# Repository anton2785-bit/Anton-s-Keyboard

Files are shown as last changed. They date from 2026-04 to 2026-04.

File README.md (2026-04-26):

# Anton-s-Keyboard
---

## What is this project

* This project is just a keyboard using 2 PCB layers. It has hotswapable switches and LEDs bellow every cap. The little oled screen will be used for brightens and lighting for the led. The rotary encoder will be volume controll. 
---
## Why i made this project
* My keyboard is starting to have some switches a little more squishi or lose compared to others. Also some of the keycaps are worn down.
* In conclusion I want to change my old keyboard with this one. 
---
# Schematic

* The shematic could be a little bit of a mess, but i had made it a month prior to this moment.
  Schematic

---
# PCB

* The PCB was redone 1 time, so that it was better with the lenght of traces and minimising the resistance.

Top layer PCB
Back layer PCB

---
# 3D case

* The case isnt perfect, but for now it will work. When i get all of the parts for the keyboard and then I will have the ability to measuer all of the things I need to make the case more percise. 
Keyboard case


* Note: The case will be 3d printed by my friend and cost free. But I will maka corections on the case once i gen the whole thing and i have the propper dimensions for the holes and the usb cable going towards the Microcontroller. 

--- 
# Firmware
* The firmware will be changed once I get access to the microcontroller.
* The code now is generated by gemini. 
* 

--- 
# Assembly steps
* First the smaller parts must be souldered first because it will be harder to soulder the smaller components once the larger ones are placed / souldered.
* Secondly the larger components are souldered.
* Thirdly the foam is placed in the bottom case.
* After that all of the other parts are placed on the foam and closed off with the top plate.
* Finaly the cable can be connected to the PC and keyboard.

---
# BOM

| Component | Purpose | Qty | Cost (USD) | Distributor |
|---|---|-----|---|---|
| Gateron Stabilizers | Prevents larger keys from wobbling | 1 lot | $9.45 | Gateron |
| Capacitors 100nF | Noise decoupling for LEDs | 2 lots | $1.61 | AliExpress |
| 5V Level Shifter (74AHCT125) | Data line shifter for LEDs | 1 | $2.95 | AliExpress |
| LEDs (SK6812 Mini-E) | Per-key underglow LEDs | 2 lots | $3.56 | AliExpress |
| Keycaps | Keycaps | 1 set | $15.78 | AliExpress |
| Rotary Encoder (EC11E) | Volume/scroll knob | 1 | $2.78 | AliExpress |
| Diodes (1N4148W) | Prevent signal backflow in matrix | 2 lots | $1.84 | AliExpress |
| OLED Screen (0.91" 128x32) | Info display | 1 | $2.35 | AliExpress |
| Tantalum Capacitor (470µF 6.3V) | Bulk power decoupling for LEDs | 1 | $3.94 | AliExpress |
| Resistors (4.7kΩ and 350Ω) | Pull-up and current limiting | 1 pack | $4.10 | AliExpress |
| Foam | Sound dampening under PCB | 1 | $7.77 | AliExpress |
| Coiled Cable | Keyboard cable | 1 | $10.77 | AliExpress |
| PCB | Board fabrication | 1 | $51.00 | JLCPCB |
| Microcontroller (YD-RP2040) | Main controller | 1 | $2.94 | AliExpress |
| Gateron Switches | Mechanical switches | 1 set | $29.00 | Gateron |
| Hotswap Sockets | Easy switch swapping | 1 lot | $6.68 | Gateron |
| **Total** | | | **$156.52** | |

---
# Aditional notes on the design choices
* The bulk capacitors and the voltage regulator if for the data line going to the LEDs on the PCB.
* The case as mentioned above " will be 3d printed by my friend and cost free. But I will maka corections on the case once i gen the whole thing and i have the propper dimensions for the holes and the usb cable going towards the Microcontroller. "
--- 
# Credits

* Designed and built by (Anton/ Anton-2785-bit)
* Inspired by open‑source mechanical keyboard and hackpad communities (https://stasis.hackclub.com/dashboard).

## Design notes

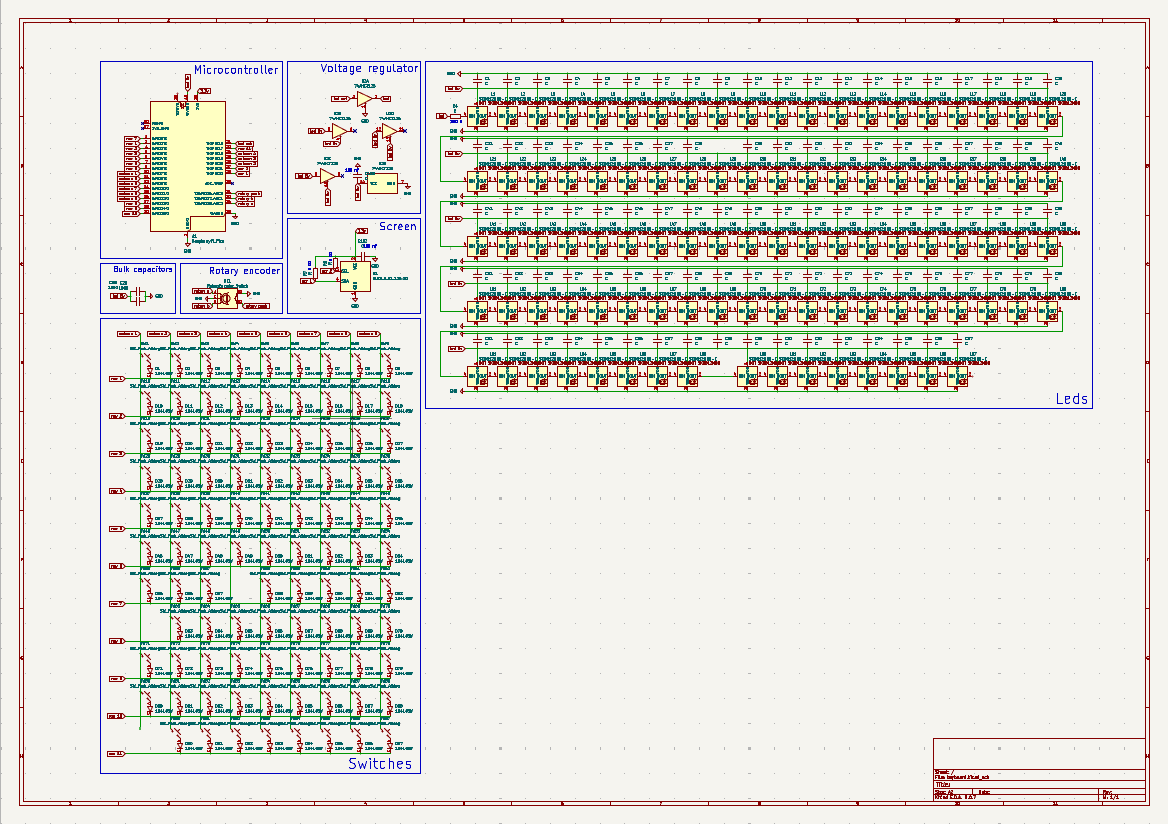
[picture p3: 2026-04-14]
Images/Schematic.png

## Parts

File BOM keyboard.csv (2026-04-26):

Product name | Product description | Product link | Product price | Product amount | Product total
Microcontroller (YD-RP 2040) | The microcontroller for the keyboard | Aliexpress | ? 2.94 | 1 | ? 2.94
Gateroon switches | These are the switches that you type on | Gateron | ? 29.00 | 1 | ? 31.94
Hotswap module | These modules allow for the easy change of the switches | Gateron | ? 6.68 | 1 | ? 38.62
Gateroon stabilizer | makes the bigger switches not wable | gateron | ? 9.45 | 1 | ? 48.07
decoupling capacitors ( 100nF ) | The capacitors are for lowering the electrical noise before the LEDs | Aliexpress | ? 1.61 | 2 | ? 51.29
5V level shifter (74AHCT125) | A 5V level shifter for the data line on the LEDs | Aliexpress | ? 2.95 | 1 | ? 54.24
LEDs (SK 6812 mini E) | The LEDs bellow the switches | Aliexpress | ? 3.56 | 2 | ? 61.36
keycaps | Keycaps | Aliexpress | ? 15.78 | 1 | ? 77.14
Rotary encoder ( EC11E ) | A knob for twisting | Aliexpress | ? 2.78 | 1 | ? 79.92
Diodes ( 1N4148W ) | Diodes, that stop form signal going back | Aliexpress | ? 1.84 | 2 | ? 83.60
Oled screen ( 0.91 inch screen 128x32) | A mini screen for displaying information | Aliexpress | ? 2.35 | 1 | ? 85.95
Tantalum capacitor ( 470uF 6.3V D ) | A bulk capacitor | Aliexpress | ? 3.94 | 1 | ? 89.89
Resistors ( Pack of many ) | Resistors ( 4.7 k? and 350?) | Aliexpress | ? 4.10 | 1 | ? 93.99
PCB | PCB | JLCPCB | ? 45.00 | 1 | ? 138.99
Foam | Used for making the keyboard sound betetr, its placed bellow the PCB | Aliexpress | ? 7.77 | 1 | ? 146.76

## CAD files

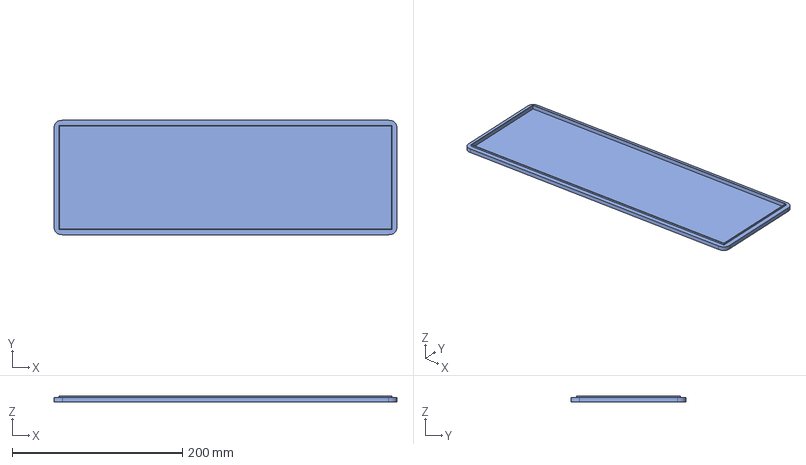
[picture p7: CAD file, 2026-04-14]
CAD/Keyboard case both parts v1/Part Studio 1 - Part 2.step
403.4 x 134.7 x 7.00 mm

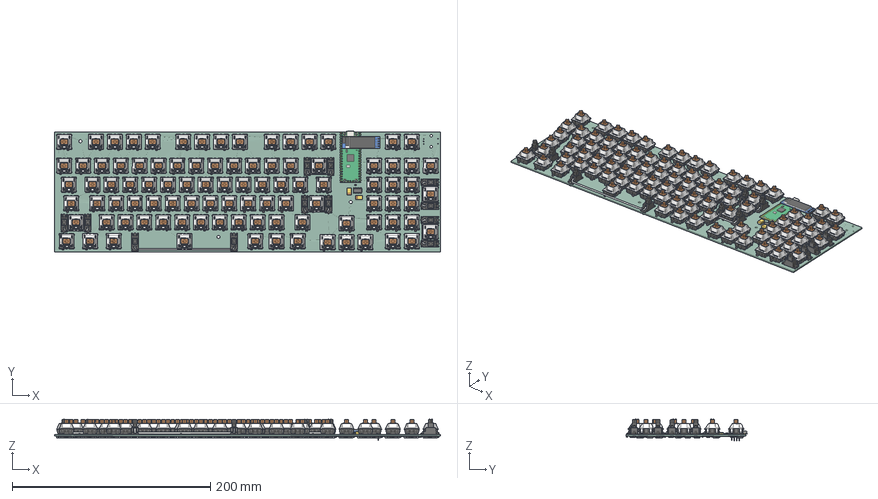
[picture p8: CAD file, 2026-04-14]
CAD/keyboard.step
389.6 x 122.3 x 21.7 mm
Pins x 96
CP_EIA-7343-31_Kemet-D x 2
C_0805_2012Metric x 98
Hotswap_MX x 96
MX_Plate x 96
Stabilizer_MX_2.00u x 5
Stabilizer_MX_6.25u
SOIC-14_3.9x8.7mm_P1.27mm
RaspberryPi_Pico_Module_KiCad
OLED_0.91_128x32
Pin Header 4 x 1 TH 2.54mm Pitch
RESC-0603 x 13
2SD0601A
Diode_SOD-123 x 96
R_0805_2012Metric x 3
keyboard_PCB

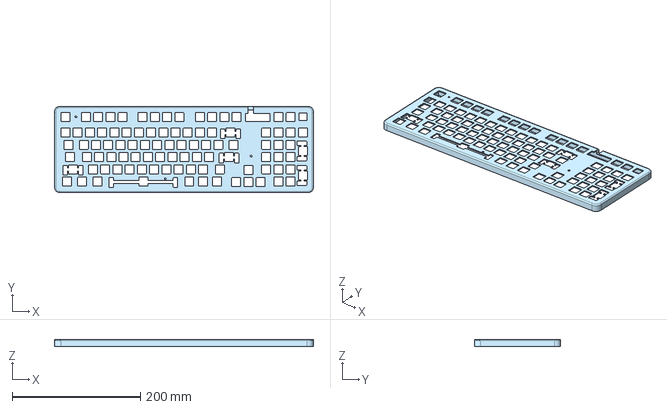
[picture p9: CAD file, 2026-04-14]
CAD/Keyboard case both parts v1/Part Studio 1 - Part 1.step
403.4 x 134.7 x 11.5 mm

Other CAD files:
Production/Bottom case.stl
Production/Top plate.stl

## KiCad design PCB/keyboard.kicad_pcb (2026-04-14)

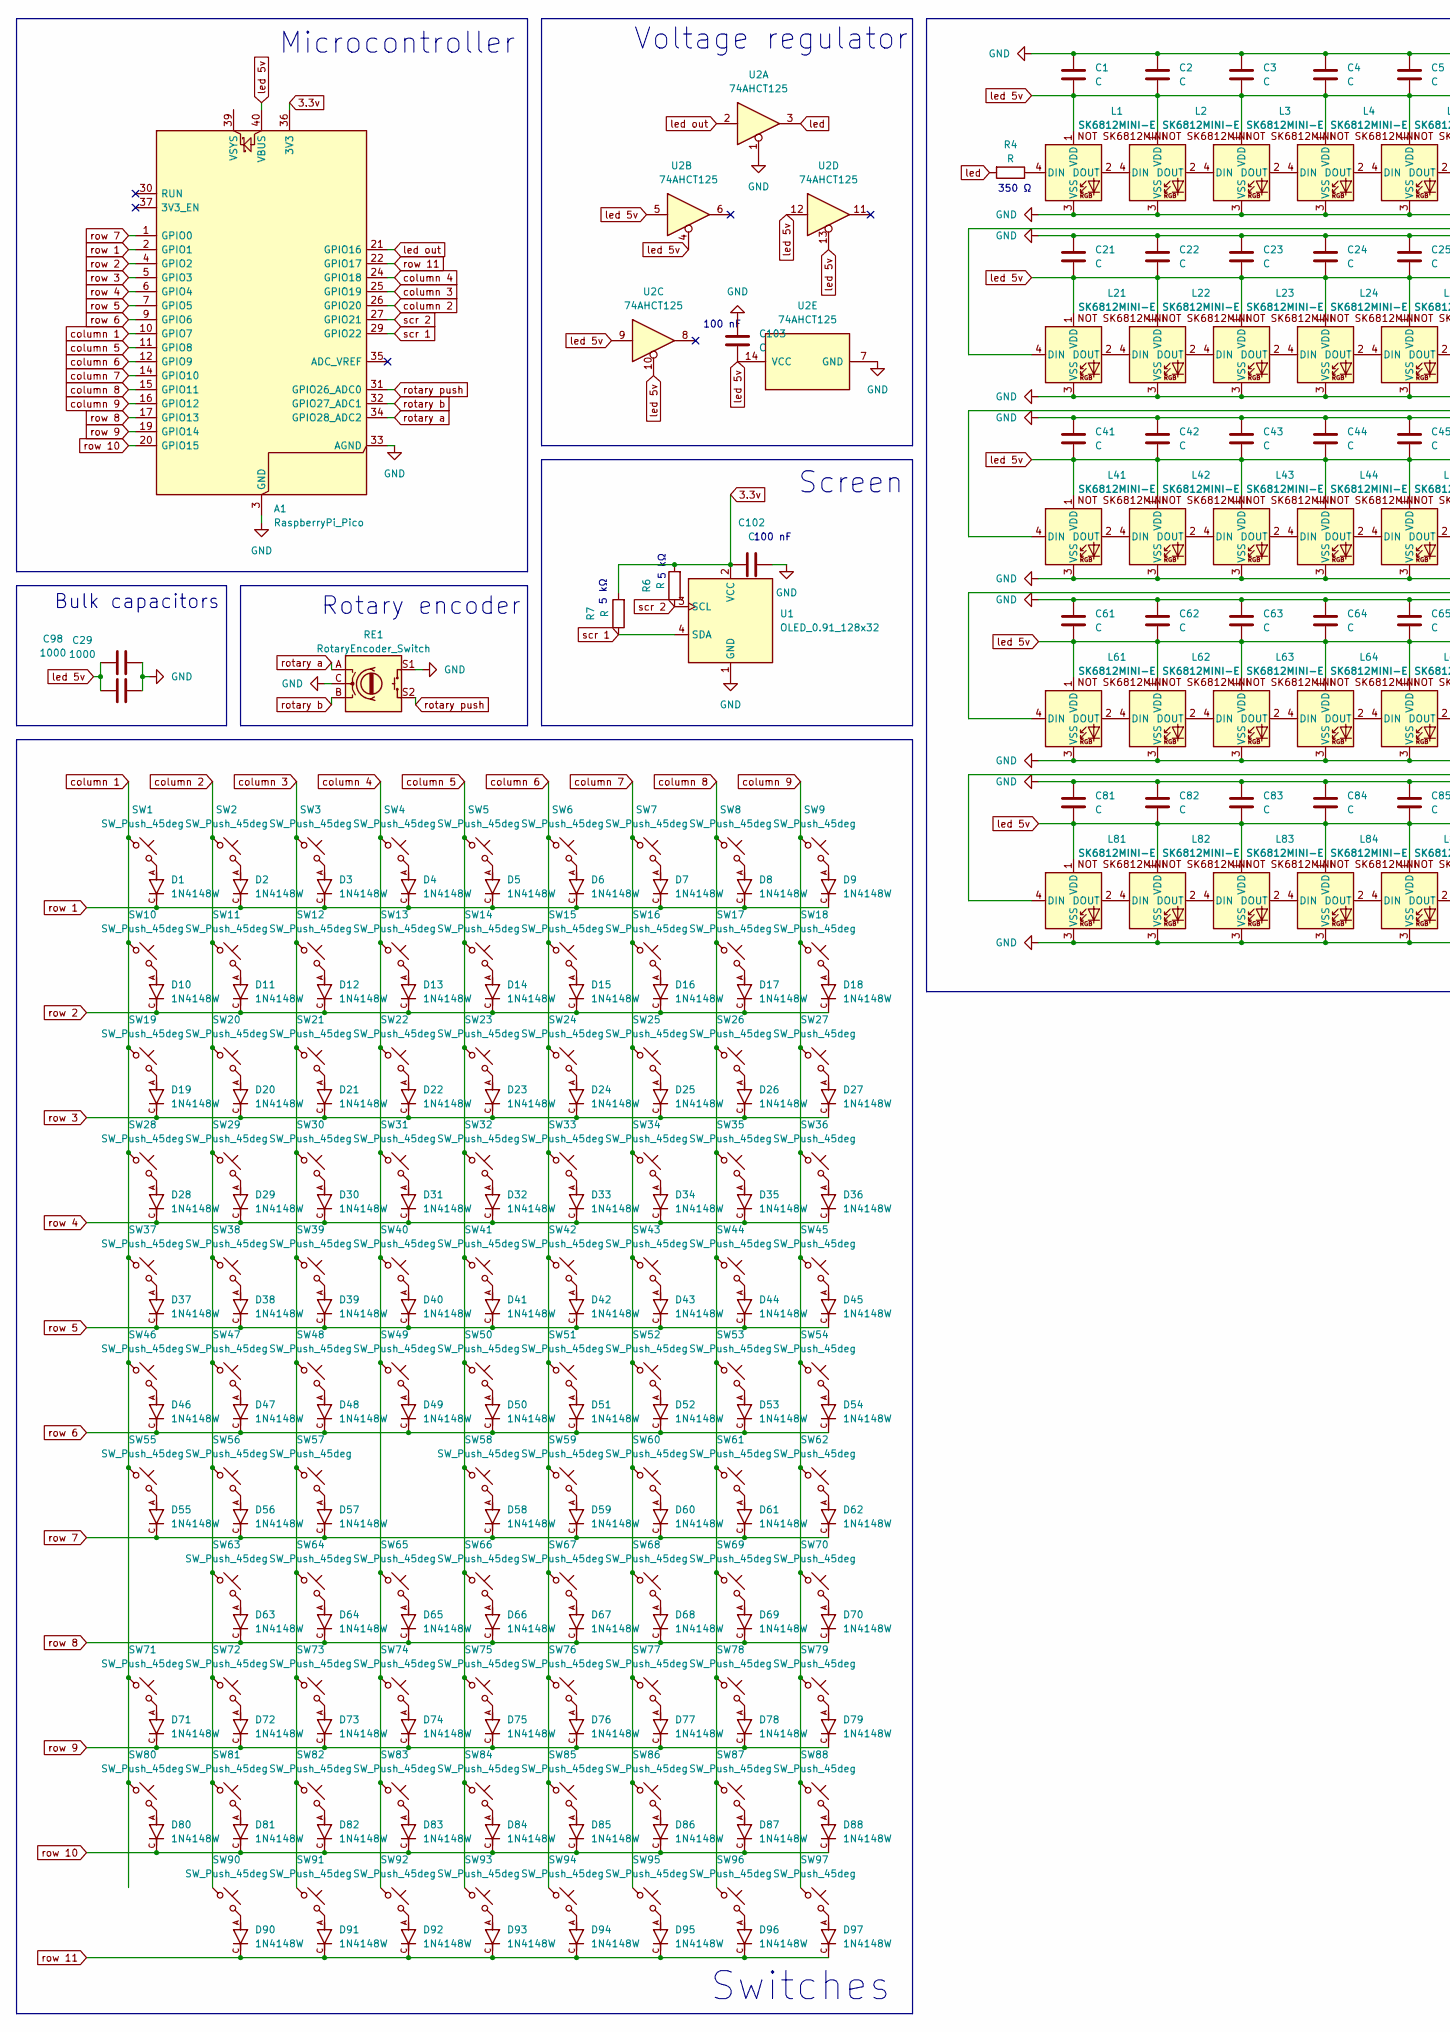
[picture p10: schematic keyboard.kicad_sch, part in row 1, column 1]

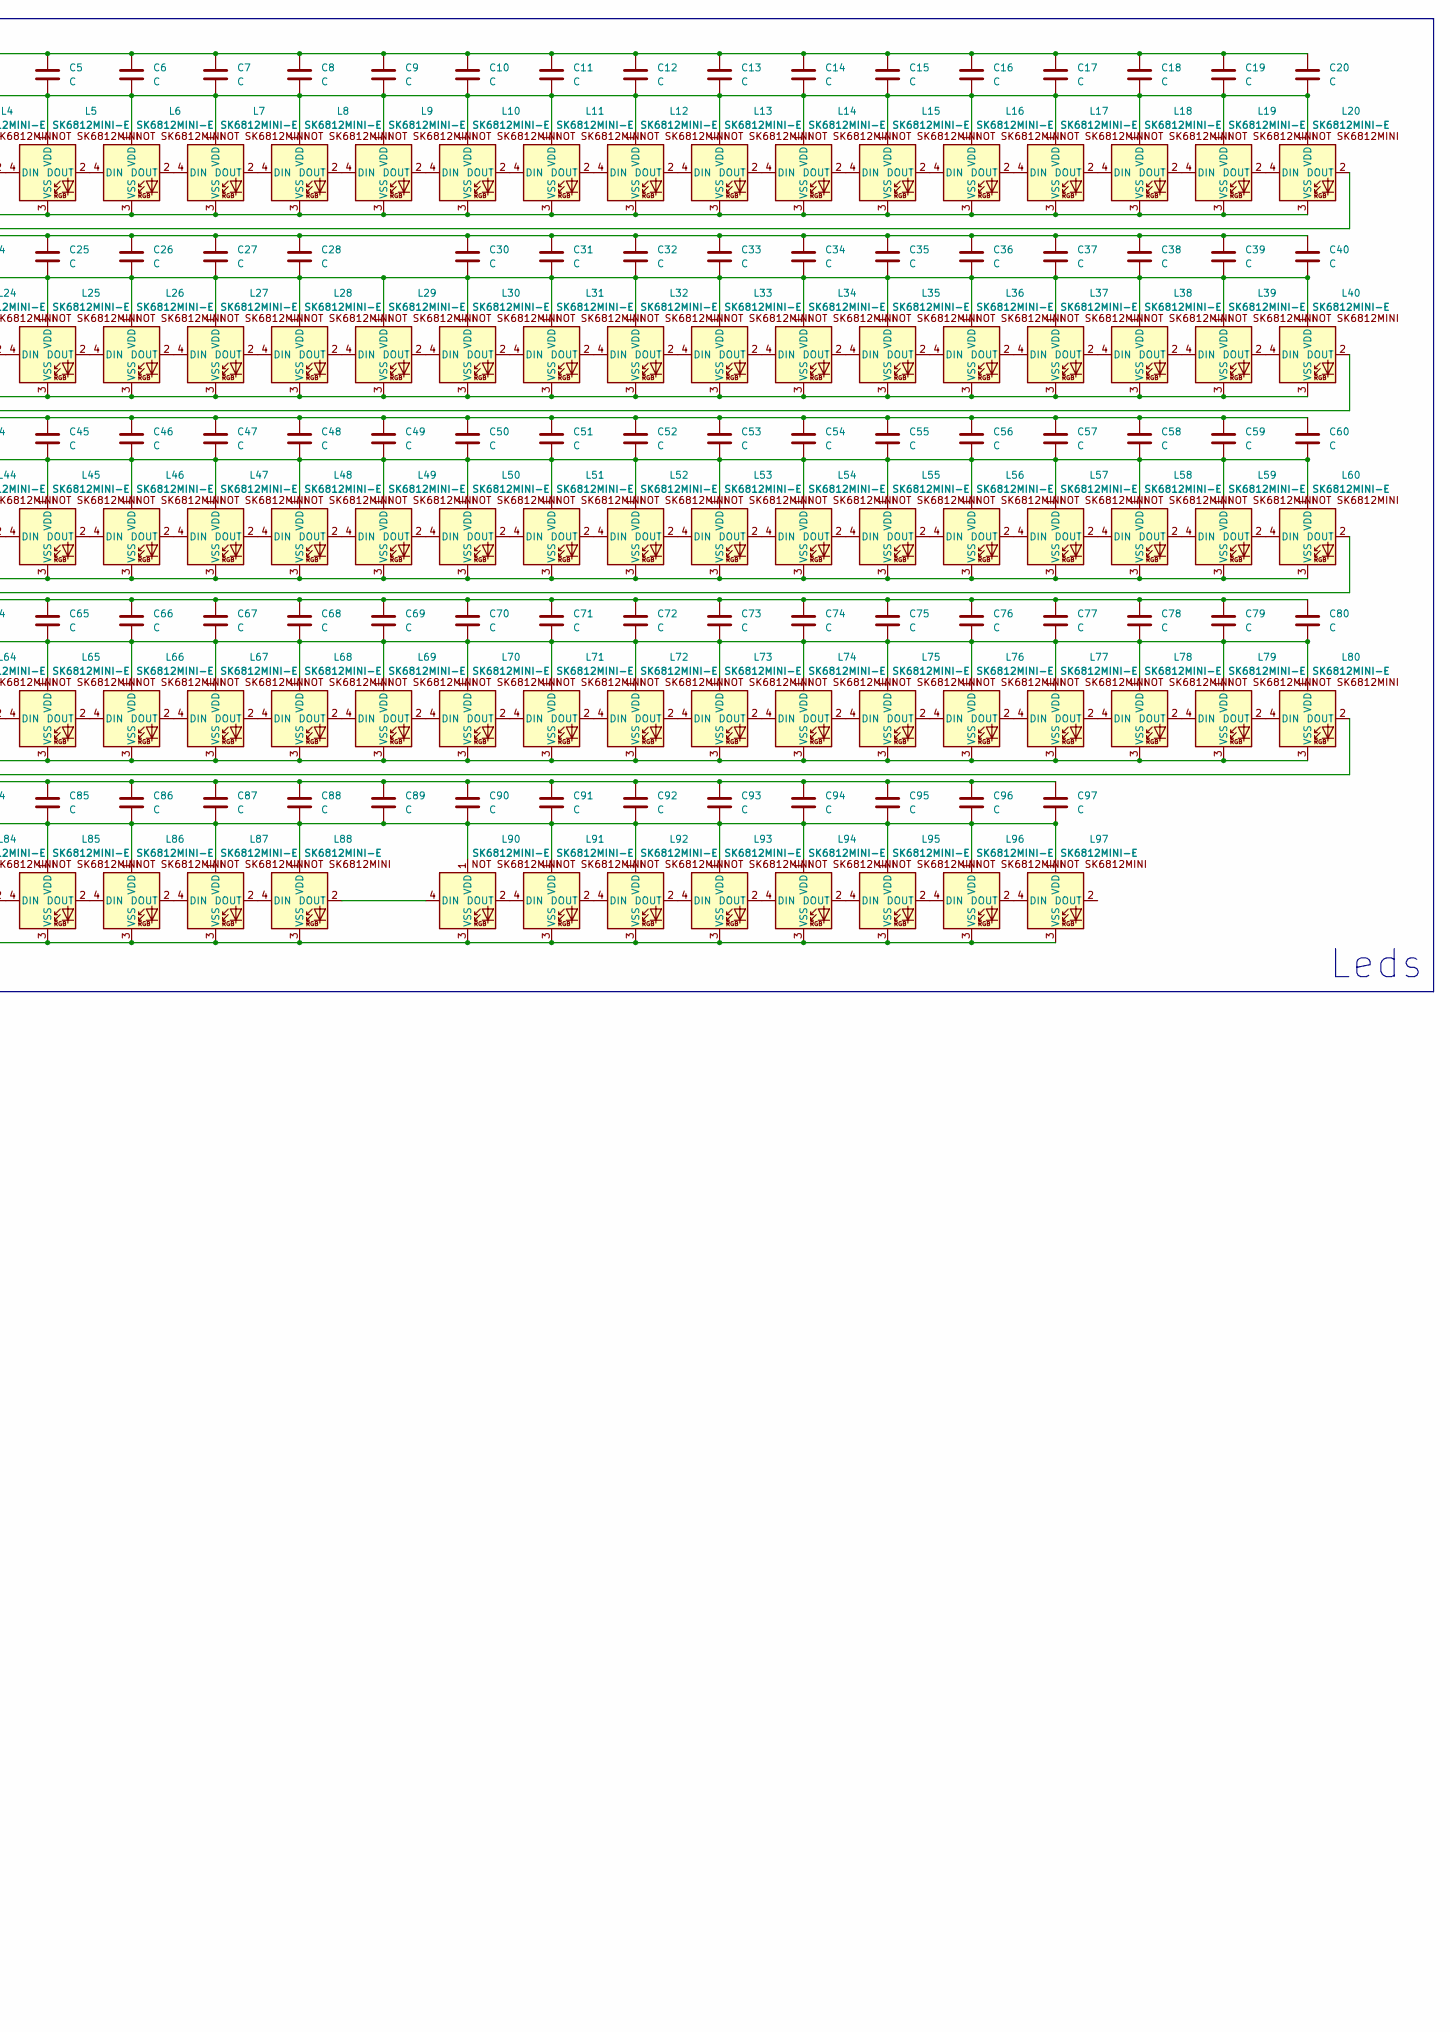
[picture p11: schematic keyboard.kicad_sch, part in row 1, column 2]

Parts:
A1: RaspberryPi_Pico; RaspberryPi_Pico_SMD_HandSolder
C1, C2, C3, C4, C5, C6, C7, C8, C9, C10, C11, C12, C13, C14, C15, C16, C17, C18, C19, C20, C21, C22, C23, C24, C25, C26, C27, C28, C30, C31, C32, C33, C34, C35, C36, C37, C38, C39, C40, C41, C42, C43, C44, C45, C46, C47, C48, C49, C50, C51, C52, C53, C54, C55, C56, C57, C58, C59, C60, C61, C62, C63, C64, C65, C66, C67, C68, C69, C70, C71, C72, C73, C74, C75, C76, C77, C78, C79, C80, C81, C82, C83, C84, C85, C86, C87, C88, C89, C90, C91, C92, C93, C94, C95, C96, C97, C102, C103: C; C_0805_2012Metric_Pad1.18x1.45mm_HandSolder
C29, C98: 1000; CP_EIA-7343-31_Kemet-D_HandSolder
D1, D2, D3, D4, D5, D6, D7, D8, D9, D10, D11, D12, D13, D14, D15, D16, D17, D18, D19, D20, D21, D22, D23, D24, D25, D26, D27, D28, D29, D30, D31, D32, D33, D34, D35, D36, D37, D38, D39, D40, D41, D42, D43, D44, D45, D46, D47, D48, D49, D50, D51, D52, D53, D54, D55, D56, D57, D58, D59, D60, D61, D62, D63, D64, D65, D66, D67, D68, D69, D70, D71, D72, D73, D74, D75, D76, D77, D78, D79, D80, D81, D82, D83, D84, D85, D86, D87, D88, D90, D91, D92, D93, D94, D95, D96, D97: 1N4148W; SODFL3816X120N; PARTREV 2021-07-12
L1, L2, L3, L4, L5, L6, L7, L8, L9, L10, L11, L12, L13, L28, L29, L30, L31, L32, L33, L34, L35, L36, L37, L38, L39, L40, L41, L55, L56, L57, L58, L59, L60, L61, L62, L63, L64, L65, L66, L67, L68, L69, L70, L74, L75, L76, L80, L81: SK6812MINI-E; MX_sk6812_mini_e_v1
L14, L15, L16, L17, L18, L19, L20, L21, L22, L23, L24, L25, L26, L27, L42, L43, L44, L45, L46, L47, L48, L49, L50, L51, L52, L53, L54, L71, L72, L73, L77, L78, L79, L82, L83, L84, L85, L86, L87, L88, L90, L91, L92, L93, L94, L95, L96, L97: SK6812MINI-E; MX_sk6812_mini_e_v1_rotated
R4, R6, R7: R; R_0805_2012Metric_Pad1.20x1.40mm_HandSolder
RE1: RotaryEncoder_Switch; RotaryEncoder_Alps_EC11E-Switch_Vertical_H20mm_CircularMoun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
SW1, SW2, SW3, SW4, SW5, SW6, SW7, SW8, SW9, SW10, SW11, SW12, SW13, SW14, SW15, SW16, SW17, SW18, SW20, SW21, SW22, SW23, SW24, SW25, SW26, SW27, SW29, SW30, SW31, SW32, SW33, SW34, SW35, SW36, SW38, SW39, SW40, SW41, SW42, SW43, SW44, SW45, SW53, SW54, SW55, SW56, SW57, SW58, SW59, SW60, SW61, SW62, SW63, SW64, SW65, SW67, SW68, SW69, SW70, SW72, SW73, SW74, SW76, SW77, SW78, SW79, SW80, SW81, SW82, SW83, SW86, SW87, SW88, SW90, SW91, SW93, SW94, SW95, SW96, SW97: SW_Push_45deg; Hotswap_MX_1.00u
SW19, SW75: SW_Push_45deg; Hotswap_MX_1.50u
SW28, SW84: SW_Push_45deg; Hotswap_MX_1.75u
SW37, SW85: SW_Push_45deg; Hotswap_MX_2.25u
SW46, SW47, SW48, SW50, SW51, SW52: SW_Push_45deg; Hotswap_MX_1.25u
SW49: SW_Push_45deg; Hotswap_MX_6.25u
SW66: SW_Push_45deg; Hotswap_MX_2.00u
SW71, SW92: SW_Push_45deg; Hotswap_MX_2.00u_90deg
U1: OLED_0.91_128x32
U2: 74AHCT125; SOIC-14_3.9x8.7mm_P1.27mm

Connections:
3.3v: A1.36 (3V3), C102.2, R6.2, R7.2, U1.2 (VCC)
GND: A1.3 (GND), A1.8 (GND), A1.13 (GND), A1.18 (GND), A1.23 (GND), A1.28 (GND), A1.33 (AGND), A1.38 (GND), C1.2, C2.2, C3.2, C4.2, C5.2, C6.2, C7.2, C8.2, C9.2, C10.2, C11.2, C12.2, C13.2, C14.2, C15.2, C16.2, C17.2, C18.2, C19.2, C20.2, C21.2, C22.2, C23.2, C24.2, C25.2, C26.2, C27.2, C28.2, C29.2, C30.2, C31.2, C32.2, C33.2, C34.2, C35.2, C36.2, C37.2, C38.2, C39.2, C40.2, C41.2, C42.2, C43.2, C44.2, C45.2, C46.2, C47.2, C48.2, C49.2, C50.2, C51.2, C52.2, C53.2, C54.2, C55.2, C56.2, C57.2, C58.2, C59.2, C60.2, C61.2, C62.2, C63.2, C64.2, C65.2, C66.2, C67.2, C68.2, C69.2, C70.2, C71.2, C72.2, C73.2, C74.2, C75.2, C76.2, C77.2, C78.2, C79.2, C80.2, C81.2, C82.2, C83.2, C84.2, C85.2, C86.2, C87.2, C88.2, C89.2, C90.2, C91.2, C92.2, C93.2, C94.2, C95.2, C96.2, C97.2, C98.2, C102.1, C103.2, L1.3 (VSS), L2.3 (VSS), L3.3 (VSS), L4.3 (VSS), L5.3 (VSS), L6.3 (VSS), L7.3 (VSS), L8.3 (VSS), L9.3 (VSS), L10.3 (VSS), L11.3 (VSS), L12.3 (VSS), L13.3 (VSS), L14.3 (VSS), L15.3 (VSS), L16.3 (VSS), L17.3 (VSS), L18.3 (VSS), L19.3 (VSS), L20.3 (VSS), L21.3 (VSS), L22.3 (VSS), L23.3 (VSS), L24.3 (VSS), L25.3 (VSS), L26.3 (VSS), L27.3 (VSS), L28.3 (VSS), L29.3 (VSS), L30.3 (VSS), L31.3 (VSS), L32.3 (VSS), L33.3 (VSS), L34.3 (VSS), L35.3 (VSS), L36.3 (VSS), L37.3 (VSS), L38.3 (VSS), L39.3 (VSS), L40.3 (VSS), L41.3 (VSS), L42.3 (VSS), L43.3 (VSS), L44.3 (VSS), L45.3 (VSS), L46.3 (VSS), L47.3 (VSS), L48.3 (VSS), L49.3 (VSS), L50.3 (VSS), L51.3 (VSS), L52.3 (VSS), L53.3 (VSS), L54.3 (VSS), L55.3 (VSS), L56.3 (VSS), L57.3 (VSS), L58.3 (VSS), L59.3 (VSS), L60.3 (VSS), L61.3 (VSS), L62.3 (VSS), L63.3 (VSS), L64.3 (VSS), L65.3 (VSS), L66.3 (VSS), L67.3 (VSS), L68.3 (VSS), L69.3 (VSS), L70.3 (VSS), L71.3 (VSS), L72.3 (VSS), L73.3 (VSS), L74.3 (VSS), L75.3 (VSS), L76.3 (VSS), L77.3 (VSS), L78.3 (VSS), L79.3 (VSS), L80.3 (VSS), L81.3 (VSS), L82.3 (VSS), L83.3 (VSS), L84.3 (VSS), L85.3 (VSS), L86.3 (VSS), L87.3 (VSS), L88.3 (VSS), L90.3 (VSS), L91.3 (VSS), L92.3 (VSS), L93.3 (VSS), L94.3 (VSS), L95.3 (VSS), L96.3 (VSS), L97.3 (VSS), RE1.C, RE1.S1, U1.1 (GND), U2.1, U2.7 (GND)
unnamed: D1.A, SW1.2
unnamed: D2.A, SW2.2
unnamed: D3.A, SW3.2
unnamed: D4.A, SW4.2
unnamed: D5.A, SW5.2
unnamed: D6.A, SW6.2
unnamed: D7.A, SW7.2
unnamed: D8.A, SW8.2
unnamed: D9.A, SW9.2
unnamed: D10.A, SW10.2
unnamed: D11.A, SW11.2
unnamed: D12.A, SW12.2
unnamed: D13.A, SW13.2
unnamed: D14.A, SW14.2
unnamed: D15.A, SW15.2
unnamed: D16.A, SW16.2
unnamed: D17.A, SW17.2
unnamed: D18.A, SW18.2
unnamed: D19.A, SW19.2
unnamed: D20.A, SW20.2
unnamed: D21.A, SW21.2
unnamed: D22.A, SW22.2
unnamed: D23.A, SW23.2
unnamed: D24.A, SW24.2
unnamed: D25.A, SW25.2
unnamed: D26.A, SW26.2
unnamed: D27.A, SW27.2
unnamed: D28.A, SW28.2
unnamed: D29.A, SW29.2
unnamed: D30.A, SW30.2
unnamed: D31.A, SW31.2
unnamed: D32.A, SW32.2
unnamed: D33.A, SW33.2
unnamed: D34.A, SW34.2
unnamed: D35.A, SW35.2
unnamed: D36.A, SW36.2
unnamed: D37.A, SW37.2
unnamed: D38.A, SW38.2
unnamed: D39.A, SW39.2
unnamed: D40.A, SW40.2
unnamed: D41.A, SW41.2
unnamed: D42.A, SW42.2
unnamed: D43.A, SW43.2
unnamed: D44.A, SW44.2
unnamed: D45.A, SW45.2
unnamed: D46.A, SW46.2
unnamed: D47.A, SW47.2
unnamed: D48.A, SW48.2
unnamed: D49.A, SW49.2
unnamed: D50.A, SW50.2
unnamed: D51.A, SW51.2
unnamed: D52.A, SW52.2
unnamed: D53.A, SW53.2
unnamed: D54.A, SW54.2
unnamed: D55.A, SW55.2
unnamed: D56.A, SW56.2
unnamed: D57.A, SW57.2
unnamed: D58.A, SW58.2
unnamed: D59.A, SW59.2
unnamed: D60.A, SW60.2
unnamed: D61.A, SW61.2
unnamed: D62.A, SW62.2
unnamed: D63.A, SW63.2
unnamed: D64.A, SW64.2
unnamed: D65.A, SW65.2
unnamed: D66.A, SW66.2
unnamed: D67.A, SW67.2
unnamed: D68.A, SW68.2
unnamed: D69.A, SW69.2
unnamed: D70.A, SW70.2
unnamed: D71.A, SW71.2
unnamed: D72.A, SW72.2
unnamed: D73.A, SW73.2
unnamed: D74.A, SW74.2
unnamed: D75.A, SW75.2
unnamed: D76.A, SW76.2
unnamed: D77.A, SW77.2
unnamed: D78.A, SW78.2
unnamed: D79.A, SW79.2
unnamed: D80.A, SW80.2
unnamed: D81.A, SW81.2
unnamed: D82.A, SW82.2
unnamed: D83.A, SW83.2
unnamed: D84.A, SW84.2
unnamed: D85.A, SW85.2
unnamed: D86.A, SW86.2
unnamed: D87.A, SW87.2
unnamed: D88.A, SW88.2
unnamed: D90.A, SW90.2
unnamed: D91.A, SW91.2
unnamed: D92.A, SW92.2
unnamed: D93.A, SW93.2
unnamed: D94.A, SW94.2
unnamed: D95.A, SW95.2
unnamed: D96.A, SW96.2
unnamed: D97.A, SW97.2
unnamed: L1.4 (DIN), R4.1
unnamed: L1.2 (DOUT), L2.4 (DIN)
unnamed: L2.2 (DOUT), L3.4 (DIN)
unnamed: L3.2 (DOUT), L4.4 (DIN)
unnamed: L4.2 (DOUT), L5.4 (DIN)
unnamed: L5.2 (DOUT), L6.4 (DIN)
unnamed: L6.2 (DOUT), L7.4 (DIN)
unnamed: L7.2 (DOUT), L8.4 (DIN)
unnamed: L8.2 (DOUT), L9.4 (DIN)
unnamed: L9.2 (DOUT), L10.4 (DIN)
unnamed: L10.2 (DOUT), L11.4 (DIN)
unnamed: L11.2 (DOUT), L12.4 (DIN)
unnamed: L12.2 (DOUT), L13.4 (DIN)
unnamed: L13.2 (DOUT), L14.4 (DIN)
unnamed: L14.2 (DOUT), L15.4 (DIN)
unnamed: L15.2 (DOUT), L16.4 (DIN)
unnamed: L16.2 (DOUT), L17.4 (DIN)
unnamed: L17.2 (DOUT), L18.4 (DIN)
unnamed: L18.2 (DOUT), L19.4 (DIN)
unnamed: L19.2 (DOUT), L20.4 (DIN)
unnamed: L20.2 (DOUT), L21.4 (DIN)
unnamed: L21.2 (DOUT), L22.4 (DIN)
unnamed: L22.2 (DOUT), L23.4 (DIN)
unnamed: L23.2 (DOUT), L24.4 (DIN)
unnamed: L24.2 (DOUT), L25.4 (DIN)
unnamed: L25.2 (DOUT), L26.4 (DIN)
unnamed: L26.2 (DOUT), L27.4 (DIN)
unnamed: L27.2 (DOUT), L28.4 (DIN)
unnamed: L28.2 (DOUT), L29.4 (DIN)
unnamed: L29.2 (DOUT), L30.4 (DIN)
unnamed: L30.2 (DOUT), L31.4 (DIN)
unnamed: L31.2 (DOUT), L32.4 (DIN)
unnamed: L32.2 (DOUT), L33.4 (DIN)
unnamed: L33.2 (DOUT), L34.4 (DIN)
unnamed: L34.2 (DOUT), L35.4 (DIN)
unnamed: L35.2 (DOUT), L36.4 (DIN)
unnamed: L36.2 (DOUT), L37.4 (DIN)
unnamed: L37.2 (DOUT), L38.4 (DIN)
unnamed: L38.2 (DOUT), L39.4 (DIN)
unnamed: L39.2 (DOUT), L40.4 (DIN)
unnamed: L40.2 (DOUT), L41.4 (DIN)
unnamed: L41.2 (DOUT), L42.4 (DIN)
unnamed: L42.2 (DOUT), L43.4 (DIN)
unnamed: L43.2 (DOUT), L44.4 (DIN)
unnamed: L44.2 (DOUT), L45.4 (DIN)
unnamed: L45.2 (DOUT), L46.4 (DIN)
unnamed: L46.2 (DOUT), L47.4 (DIN)
unnamed: L47.2 (DOUT), L48.4 (DIN)
unnamed: L48.2 (DOUT), L49.4 (DIN)
unnamed: L49.2 (DOUT), L50.4 (DIN)
unnamed: L50.2 (DOUT), L51.4 (DIN)
unnamed: L51.2 (DOUT), L52.4 (DIN)
unnamed: L52.2 (DOUT), L53.4 (DIN)
unnamed: L53.2 (DOUT), L54.4 (DIN)
unnamed: L54.2 (DOUT), L55.4 (DIN)
unnamed: L55.2 (DOUT), L56.4 (DIN)
unnamed: L56.2 (DOUT), L57.4 (DIN)
unnamed: L57.2 (DOUT), L58.4 (DIN)
unnamed: L58.2 (DOUT), L59.4 (DIN)
unnamed: L59.2 (DOUT), L60.4 (DIN)
unnamed: L60.2 (DOUT), L61.4 (DIN)
unnamed: L61.2 (DOUT), L62.4 (DIN)
unnamed: L62.2 (DOUT), L63.4 (DIN)
unnamed: L63.2 (DOUT), L64.4 (DIN)
unnamed: L64.2 (DOUT), L65.4 (DIN)
unnamed: L65.2 (DOUT), L66.4 (DIN)
unnamed: L66.2 (DOUT), L67.4 (DIN)
unnamed: L67.2 (DOUT), L68.4 (DIN)
unnamed: L68.2 (DOUT), L69.4 (DIN)
unnamed: L69.2 (DOUT), L70.4 (DIN)
unnamed: L70.2 (DOUT), L71.4 (DIN)
unnamed: L71.2 (DOUT), L72.4 (DIN)
unnamed: L72.2 (DOUT), L73.4 (DIN)
unnamed: L73.2 (DOUT), L74.4 (DIN)
unnamed: L74.2 (DOUT), L75.4 (DIN)
unnamed: L75.2 (DOUT), L76.4 (DIN)
unnamed: L76.2 (DOUT), L77.4 (DIN)
unnamed: L77.2 (DOUT), L78.4 (DIN)
unnamed: L78.2 (DOUT), L79.4 (DIN)
unnamed: L79.2 (DOUT), L80.4 (DIN)
unnamed: L80.2 (DOUT), L81.4 (DIN)
unnamed: L81.2 (DOUT), L82.4 (DIN)
unnamed: L82.2 (DOUT), L83.4 (DIN)
unnamed: L83.2 (DOUT), L84.4 (DIN)
unnamed: L84.2 (DOUT), L85.4 (DIN)
unnamed: L85.2 (DOUT), L86.4 (DIN)
unnamed: L86.2 (DOUT), L87.4 (DIN)
unnamed: L87.2 (DOUT), L88.4 (DIN)
unnamed: L88.2 (DOUT), L90.4 (DIN)
unnamed: L90.2 (DOUT), L91.4 (DIN)
unnamed: L91.2 (DOUT), L92.4 (DIN)
unnamed: L92.2 (DOUT), L93.4 (DIN)
unnamed: L93.2 (DOUT), L94.4 (DIN)
unnamed: L94.2 (DOUT), L95.4 (DIN)
unnamed: L95.2 (DOUT), L96.4 (DIN)
unnamed: L96.2 (DOUT), L97.4 (DIN)
column 1: A1.10 (GPIO7), SW1.1, SW10.1, SW19.1, SW28.1, SW37.1, SW46.1, SW55.1, SW71.1, SW80.1
column 2: A1.26 (GPIO20), SW2.1, SW11.1, SW20.1, SW29.1, SW38.1, SW47.1, SW56.1, SW63.1, SW72.1, SW81.1, SW90.1
column 3: A1.25 (GPIO19), SW3.1, SW12.1, SW21.1, SW30.1, SW39.1, SW48.1, SW57.1, SW64.1, SW73.1, SW82.1, SW91.1
column 4: A1.24 (GPIO18), SW4.1, SW13.1, SW22.1, SW31.1, SW40.1, SW49.1, SW65.1, SW74.1, SW83.1, SW92.1
column 5: A1.11 (GPIO8), SW5.1, SW14.1, SW23.1, SW32.1, SW41.1, SW50.1, SW58.1, SW66.1, SW75.1, SW84.1, SW93.1
column 6: A1.12 (GPIO9), SW6.1, SW15.1, SW24.1, SW33.1, SW42.1, SW51.1, SW59.1, SW67.1, SW76.1, SW85.1, SW94.1
column 7: A1.14 (GPIO10), SW7.1, SW16.1, SW25.1, SW34.1, SW43.1, SW52.1, SW60.1, SW68.1, SW77.1, SW86.1, SW95.1
column 8: A1.15 (GPIO11), SW8.1, SW17.1, SW26.1, SW35.1, SW44.1, SW53.1, SW61.1, SW69.1, SW78.1, SW87.1, SW96.1
column 9: A1.16 (GPIO12), SW9.1, SW18.1, SW27.1, SW36.1, SW45.1, SW54.1, SW62.1, SW70.1, SW79.1, SW88.1, SW97.1
led: R4.2, U2.3
led 5v: A1.40 (VBUS), C1.1, C2.1, C3.1, C4.1, C5.1, C6.1, C7.1, C8.1, C9.1, C10.1, C11.1, C12.1, C13.1, C14.1, C15.1, C16.1, C17.1, C18.1, C19.1, C20.1, C21.1, C22.1, C23.1, C24.1, C25.1, C26.1, C27.1, C28.1, C29.1, C30.1, C31.1, C32.1, C33.1, C34.1, C35.1, C36.1, C37.1, C38.1, C39.1, C40.1, C41.1, C42.1, C43.1, C44.1, C45.1, C46.1, C47.1, C48.1, C49.1, C50.1, C51.1, C52.1, C53.1, C54.1, C55.1, C56.1, C57.1, C58.1, C59.1, C60.1, C61.1, C62.1, C63.1, C64.1, C65.1, C66.1, C67.1, C68.1, C69.1, C70.1, C71.1, C72.1, C73.1, C74.1, C75.1, C76.1, C77.1, C78.1, C79.1, C80.1, C81.1, C82.1, C83.1, C84.1, C85.1, C86.1, C87.1, C88.1, C89.1, C90.1, C91.1, C92.1, C93.1, C94.1, C95.1, C96.1, C97.1, C98.1, C103.1, L1.1 (VDD), L2.1 (VDD), L3.1 (VDD), L4.1 (VDD), L5.1 (VDD), L6.1 (VDD), L7.1 (VDD), L8.1 (VDD), L9.1 (VDD), L10.1 (VDD), L11.1 (VDD), L12.1 (VDD), L13.1 (VDD), L14.1 (VDD), L15.1 (VDD), L16.1 (VDD), L17.1 (VDD), L18.1 (VDD), L19.1 (VDD), L20.1 (VDD), L21.1 (VDD), L22.1 (VDD), L23.1 (VDD), L24.1 (VDD), L25.1 (VDD), L26.1 (VDD), L27.1 (VDD), L28.1 (VDD), L29.1 (VDD), L30.1 (VDD), L31.1 (VDD), L32.1 (VDD), L33.1 (VDD), L34.1 (VDD), L35.1 (VDD), L36.1 (VDD), L37.1 (VDD), L38.1 (VDD), L39.1 (VDD), L40.1 (VDD), L41.1 (VDD), L42.1 (VDD), L43.1 (VDD), L44.1 (VDD), L45.1 (VDD), L46.1 (VDD), L47.1 (VDD), L48.1 (VDD), L49.1 (VDD), L50.1 (VDD), L51.1 (VDD), L52.1 (VDD), L53.1 (VDD), L54.1 (VDD), L55.1 (VDD), L56.1 (VDD), L57.1 (VDD), L58.1 (VDD), L59.1 (VDD), L60.1 (VDD), L61.1 (VDD), L62.1 (VDD), L63.1 (VDD), L64.1 (VDD), L65.1 (VDD), L66.1 (VDD), L67.1 (VDD), L68.1 (VDD), L69.1 (VDD), L70.1 (VDD), L71.1 (VDD), L72.1 (VDD), L73.1 (VDD), L74.1 (VDD), L75.1 (VDD), L76.1 (VDD), L77.1 (VDD), L78.1 (VDD), L79.1 (VDD), L80.1 (VDD), L81.1 (VDD), L82.1 (VDD), L83.1 (VDD), L84.1 (VDD), L85.1 (VDD), L86.1 (VDD), L87.1 (VDD), L88.1 (VDD), L90.1 (VDD), L91.1 (VDD), L92.1 (VDD), L93.1 (VDD), L94.1 (VDD), L95.1 (VDD), L96.1 (VDD), L97.1 (VDD), U2.4, U2.5, U2.9, U2.10, U2.12, U2.13, U2.14 (VCC)
led out: A1.21 (GPIO16), U2.2
rotary a: A1.34 (GPIO28_ADC2), RE1.A
rotary b: A1.32 (GPIO27_ADC1), RE1.B
rotary push: A1.31 (GPIO26_ADC0), RE1.S2
row 1: A1.2 (GPIO1), D1.C, D2.C, D3.C, D4.C, D5.C, D6.C, D7.C, D8.C, D9.C
row 2: A1.4 (GPIO2), D10.C, D11.C, D12.C, D13.C, D14.C, D15.C, D16.C, D17.C, D18.C
row 3: A1.5 (GPIO3), D19.C, D20.C, D21.C, D22.C, D23.C, D24.C, D25.C, D26.C, D27.C
row 4: A1.6 (GPIO4), D28.C, D29.C, D30.C, D31.C, D32.C, D33.C, D34.C, D35.C, D36.C
row 5: A1.7 (GPIO5), D37.C, D38.C, D39.C, D40.C, D41.C, D42.C, D43.C, D44.C, D45.C
row 6: A1.9 (GPIO6), D46.C, D47.C, D48.C, D49.C, D50.C, D51.C, D52.C, D53.C, D54.C
row 7: A1.1 (GPIO0), D55.C, D56.C, D57.C, D58.C, D59.C, D60.C, D61.C, D62.C
row 8: A1.17 (GPIO13), D63.C, D64.C, D65.C, D66.C, D67.C, D68.C, D69.C, D70.C
row 9: A1.19 (GPIO14), D71.C, D72.C, D73.C, D74.C, D75.C, D76.C, D77.C, D78.C, D79.C
row 10: A1.20 (GPIO15), D80.C, D81.C, D82.C, D83.C, D84.C, D85.C, D86.C, D87.C, D88.C
row 11: A1.22 (GPIO17), D90.C, D91.C, D92.C, D93.C, D94.C, D95.C, D96.C, D97.C
scr 1: A1.29 (GPIO22), R7.1, U1.4 (SDA)
scr 2: A1.27 (GPIO21), R6.1, U1.3 (SCL)

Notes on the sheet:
Rotary encoder
Switches
Microcontroller
5 kΩ
100 nF
Bulk capacitors
Screen
Voltage regulator
Leds
350 Ω

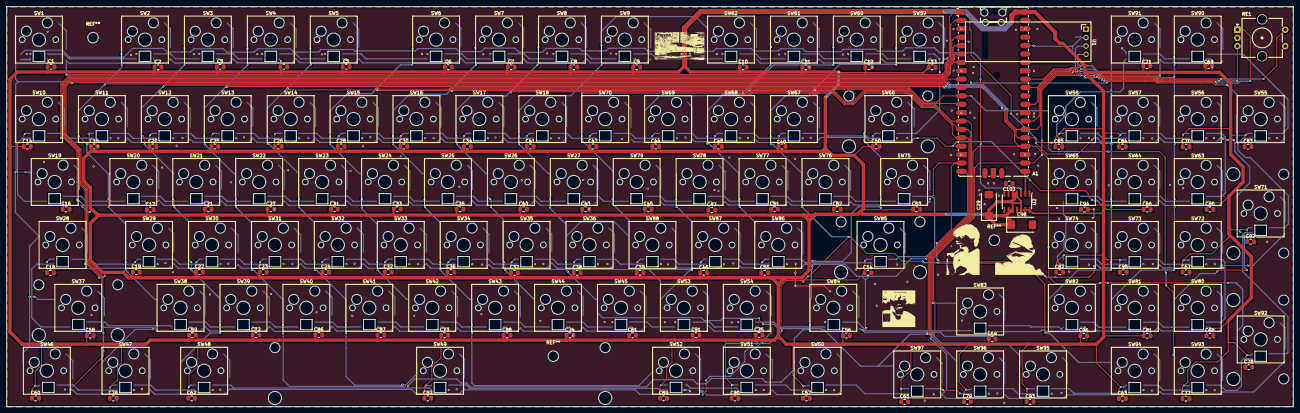
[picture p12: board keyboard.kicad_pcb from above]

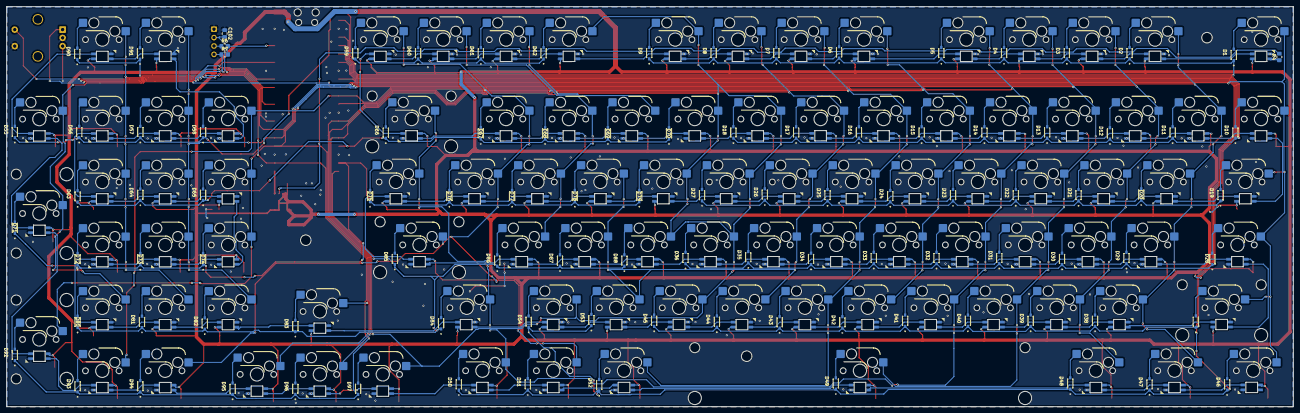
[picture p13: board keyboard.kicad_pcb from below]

Board: 2 copper layers, 389.6 x 121.1 mm, 395 parts (100 on the bottom side), 222 nets.

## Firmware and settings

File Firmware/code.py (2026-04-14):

import board
from kmk.kmk_keyboard import KMKKeyboard
from kmk.keys import KC
from kmk.scanners import DiodeOrientation
from kmk.extensions.RGB import RGB
from kmk.modules.encoder import Encoder
from kmk.modules.layers import Layers

keyboard = KMKKeyboard()
keyboard.modules.append(Layers())

# 1. 11 Rows x 9 Columns Matrix Configuration
keyboard.row_pins = (
    board.GP11, board.GP12, board.GP13, board.GP14, board.GP15, 
    board.GP16, board.GP17, board.GP18, board.GP19, board.GP20, board.GP21
)
keyboard.col_pins = (
    board.GP0, board.GP1, board.GP2, board.GP3, board.GP4, 
    board.GP5, board.GP6, board.GP7, board.GP8
)
keyboard.diode_orientation = DiodeOrientation.COL2ROW

# 2. RGB LED Configuration (50% Power Safety)
# val_limit=128 prevents the LEDs from drawing too much current
rgb = RGB(
    pixel_pin=board.GP22, 
    num_pixels=96, 
    val_limit=128, 
    hue_default=0, 
    sat_default=0, 
    val_default=100
)
keyboard.extensions.append(rgb)

# 3. Rotary Encoder (A & B Pins)
encoder = Encoder()
encoder.pins = (
    (board.GP26, board.GP27, None), # Rotation Pins (A, B). Push is in Matrix.
)
# Layer 0: Volume | Layer 1: LED Brightness
encoder.map = [
    ((KC.VOLU, KC.VOLD),),        # Standard Mode
    ((KC.RGB_VAI, KC.RGB_VAD),),  # FN Mode (Brightness Up/Down)
]
keyboard.modules.append(encoder)

# 4. 1800 Layout Matrix (11x9)
# Note: 'KC.MO(1)' is your Function key. Hold it to use the 2nd encoder mode.
# I've mapped the Encoder Push to KC.MUTE.
keyboard.keymap = [
    # LAYER 0: Standard
    [
        KC.ESC,  KC.F1,   KC.F2,   KC.F3,   KC.F4,   KC.F5,   KC.F6,   KC.F7,   KC.F8,
        KC.F9,   KC.F10,  KC.F11,  KC.F12,  KC.PSCR, KC.SLCK, KC.PAUS, KC.GRV,  KC.1,
        KC.2,    KC.3,    KC.4,    KC.5,    KC.6,    KC.7,    KC.8,    KC.9,    KC.0,
        KC.MINS, KC.EQL,  KC.BSPC, KC.INS,  KC.HOME, KC.PGUP, KC.TAB,  KC.Q,    KC.W,
        KC.E,    KC.R,    KC.T,    KC.Y,    KC.U,    KC.I,    KC.O,    KC.P,    KC.LBRC,
        KC.RBRC, KC.BSLS, KC.DEL,  KC.END,  KC.PGDN, KC.CAPS, KC.A,    KC.S,    KC.D,
        KC.F,    KC.G,    KC.H,    KC.J,    KC.K,    KC.L,    KC.SCLN, KC.QUOT, KC.ENT,
        KC.P7,   KC.P8,   KC.P9,   KC.LSFT, KC.Z,    KC.X,    KC.C,    KC.V,    KC.B,
        KC.N,    KC.M,    KC.COMM, KC.DOT,  KC.SLSH, KC.RSFT, KC.UP,   KC.P4,   KC.P5,
        KC.P6,   KC.LCTL, KC.LGUI, KC.LALT, KC.SPC,  KC.RALT, KC.MO(1),KC.RCTL, KC.LEFT,
        KC.DOWN, KC.RGHT, KC.P1,   KC.P2,   KC.P3,   KC.PENT, KC.P0,   KC.PDOT, KC.MUTE
    ],
    # LAYER 1: Function (Add specific FN keys here if needed)
    [
        KC.TRNS, KC.TRNS, KC.TRNS, KC.TRNS, KC.TRNS, KC.TRNS, KC.TRNS, KC.TRNS, KC.TRNS,
        KC.TRNS, KC.TRNS, KC.TRNS, KC.TRNS, KC.TRNS, KC.TRNS, KC.TRNS, KC.TRNS, KC.TRNS,
        KC.TRNS, KC.TRNS, KC.TRNS, KC.TRNS, KC.TRNS, KC.TRNS, KC.TRNS, KC.TRNS, KC.TRNS,
        KC.TRNS, KC.TRNS, KC.TRNS, KC.TRNS, KC.TRNS, KC.TRNS, KC.TRNS, KC.TRNS, KC.TRNS,
        KC.TRNS, KC.TRNS, KC.TRNS, KC.TRNS, KC.TRNS, KC.TRNS, KC.TRNS, KC.TRNS, KC.TRNS,
        KC.TRNS, KC.TRNS, KC.TRNS, KC.TRNS, KC.TRNS, KC.TRNS, KC.TRNS, KC.TRNS, KC.TRNS,
        KC.TRNS, KC.TRNS, KC.TRNS, KC.TRNS, KC.TRNS, KC.TRNS, KC.TRNS, KC.TRNS, KC.TRNS,
        KC.TRNS, KC.TRNS, KC.TRNS, KC.TRNS, KC.TRNS, KC.TRNS, KC.TRNS, KC.TRNS, KC.TRNS,
        KC.TRNS, KC.TRNS, KC.TRNS, KC.TRNS, KC.TRNS, KC.TRNS, KC.TRNS, KC.TRNS, KC.TRNS,
        KC.TRNS, KC.TRNS, KC.TRNS, KC.TRNS, KC.TRNS, KC.TRNS, KC.TRNS, KC.TRNS, KC.TRNS,
        KC.TRNS, KC.TRNS, KC.TRNS, KC.TRNS, KC.TRNS, KC.TRNS, KC.TRNS, KC.TRNS, KC.TRNS
    ]
]

if __name__ == '__main__':
    keyboard.go()
